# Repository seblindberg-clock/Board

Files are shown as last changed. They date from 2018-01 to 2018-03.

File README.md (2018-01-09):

## Clock Board

Mechanical design

## Revisions

Board revisions are kept as tags in git. The board is generally tagged when the files have been sent off for manufacturing. To export a specific revision, simply run

```
$ git archive --format zip -o /path/to/rev-a.zip 4d268f
```

where the hash of the tag can be found by running `git show rev-a` for the specific tag.

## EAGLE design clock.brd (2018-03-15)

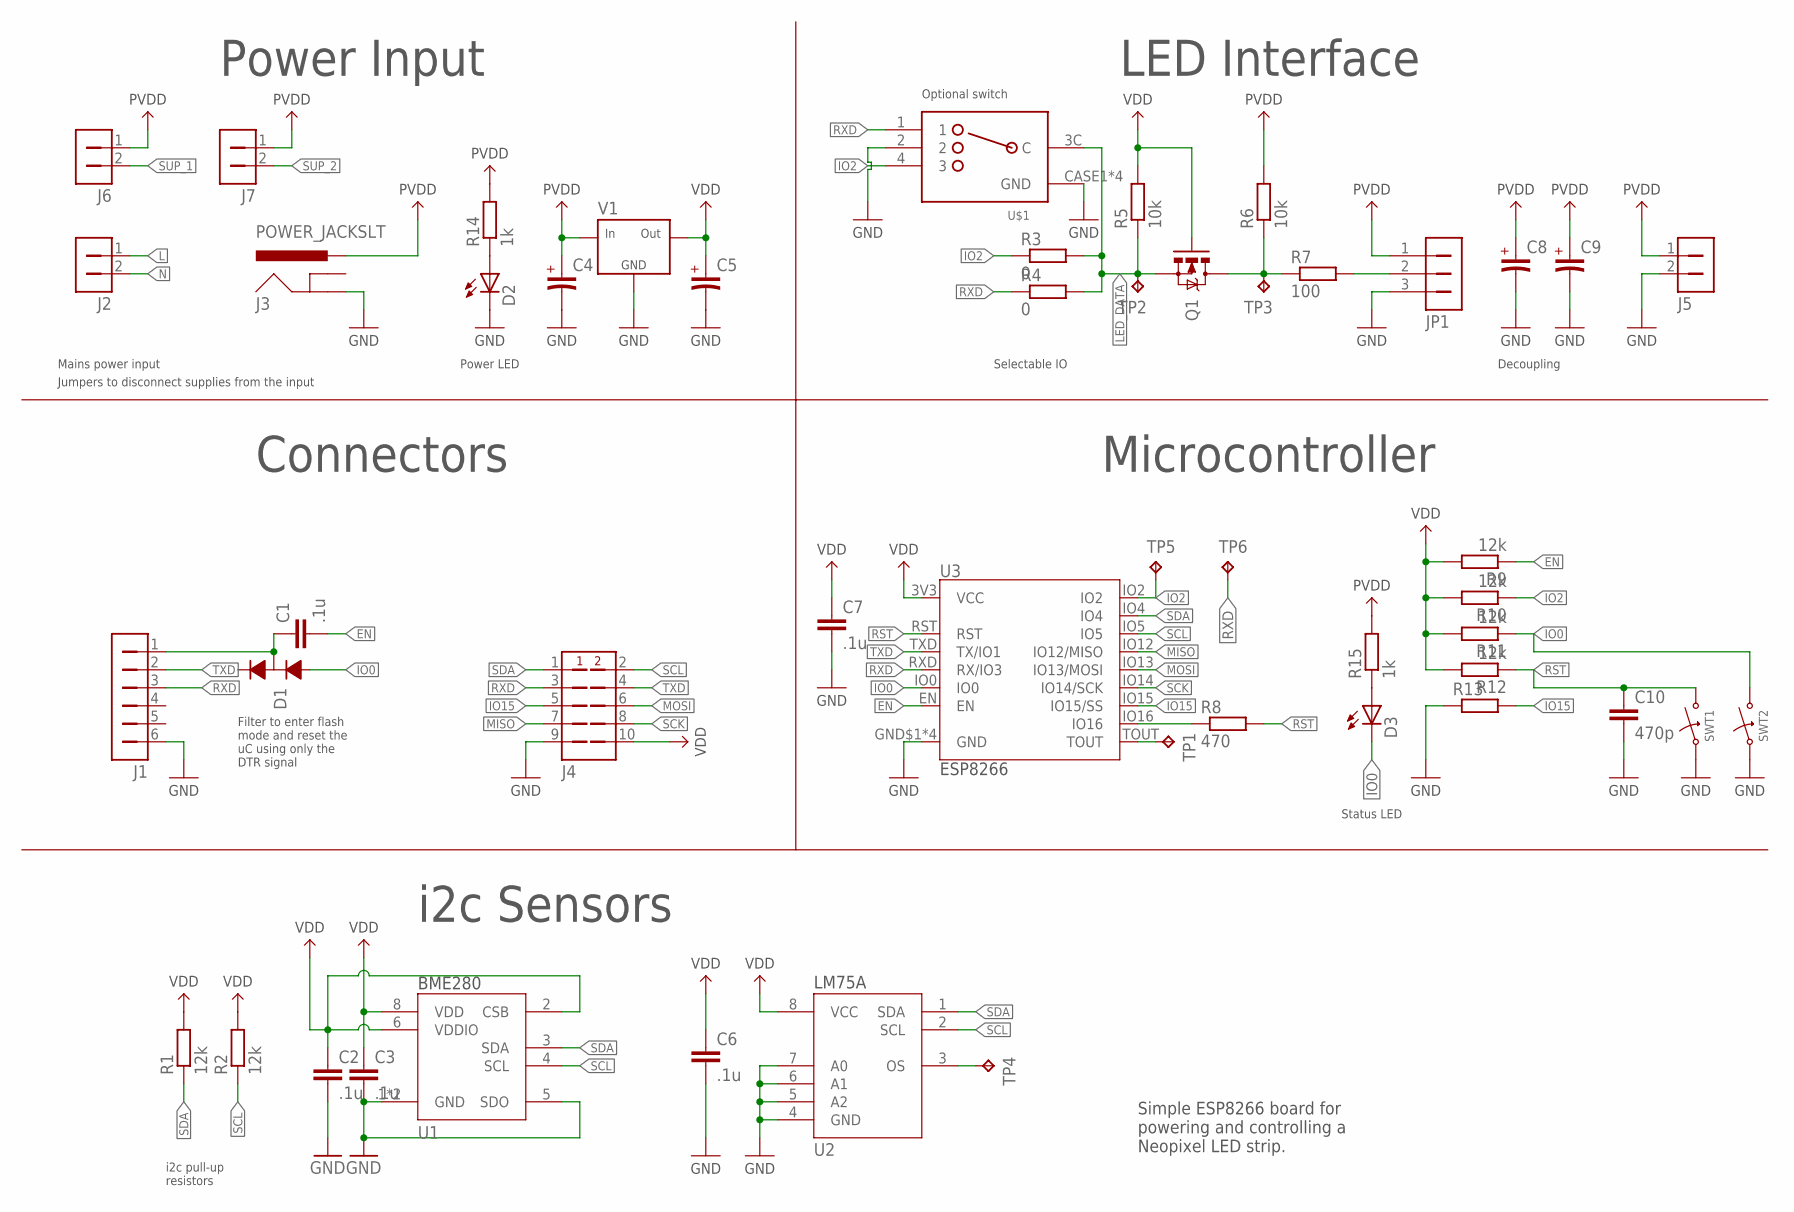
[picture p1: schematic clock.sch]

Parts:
C1, C2, C3, C6, C7: .1u; 0603
C4, C5: C_POL_1206; 1206_POL
C8, C9: C_POL_AVE_X; AVE_X
C10: 470p; 0603
D1: SBAV99WT1G; SC70
D2, D3: LED_0805; 0805_LED
J1: 1X6_RIGHT
J2: 1X2_IEC_C8_RIGHT; IEC_C8_RIGHT
J3: POWER_JACKSLT; POWER_JACK_SLOT
J4: 2X5
J5: 1X2_MOLEX_53254
J6, J7: 1X2
JP1: 1X3_MOLEX_53254
Q1: NMOS_2N7002; SOT23
R1, R2, R9, R10, R11, R12: 12k; 0603
R3, R4: 0; 0603
R5, R6: 10k; 0603
R7: 100; 0603
R8: 470; 0603
R13: R_0603; 0603
R14, R15: 1k; 0603
SWT1, SWT2: BUTTON_SMD_2P; BTN_SMD_2PIN
TP1, TP2, TP3, TP4, TP5, TP6: TPTP15R; TP15R
U1: BME280
U2: LM75A_SO8; SO8
U3: ESP8266_13; ESP13
U$1: SWITCH_1P3T_SSSS812201; SSSS812201
V1: NCP1117; TO252

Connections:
EN: C1.2, R9.1, U3.EN
GND: C2.2, C3.2, C4.2, C5.2, C6.2, C7.2, C8.- (2), C9.- (2), C10.2, D2.C, J1.6, J3.GND@2 (GND), J4.9, J5.2, JP1.3, R13.1, SWT1.1, SWT2.1, U1.1 (GND), U1.5 (SDO), U1.7 (GND), U2.4 (GND), U2.5 (A2), U2.6 (A1), U2.7 (A0), U3.GND$1 (GND), U3.GND$2 (GND), U3.GND$3 (GND), U3.GND$4 (GND), U$1.2, U$1.CASE1 (GND), U$1.CASE2 (GND), U$1.CASE3 (GND), U$1.CASE4 (GND), V1.1 (GND)
IO0: D1.1 (ANODE), D3.C, R11.1, SWT2.2, U3.IO0
IO2: R3.1, R10.1, TP5.TP, U3.IO2, U$1.4 (3)
IO15: J4.5, R13.2, U3.IO15 (IO15/SS)
L: J2.1
LED_DATA: Q1.2 (S), R3.2, R4.2, R5.1, TP2.TP, U$1.3C (C)
MISO: J4.7, U3.IO12 (IO12/MISO)
MOSI: J4.6, U3.IO13 (IO13/MOSI)
N: J2.2
unnamed: TP4.TP, U2.3 (OS)
unnamed: Q1.3 (D), R6.1, R7.1, TP3.TP
unnamed: JP1.2, R7.2
unnamed: D2.A, R14.1
unnamed: D3.A, R15.1
unnamed: TP1.TP, U3.TOUT
unnamed: R8.1, U3.IO16
unnamed: C1.1, D1.3 (MIDDLE), J1.1
PVDD: C4.1, C8.+ (1), C9.+ (1), J3.PWR, J5.1, J6.1, J7.1, JP1.1, R6.2, R14.2, R15.2, V1.2 (IN)
RST: C10.1, R8.2, R12.1, SWT1.2, U3.RST
RXD: J1.3, J4.3, R4.1, TP6.TP, U3.RXD (RX/IO3), U$1.1
SCK: J4.8, U3.IO14 (IO14/SCK)
SCL: J4.2, R2.1, U1.4 (SCL), U2.2 (SCL), U3.IO5
SDA: J4.1, R1.1, U1.3 (SDA), U2.1 (SDA), U3.IO4
SUP_1: J6.2
SUP_2: J7.2
TXD: J1.2, J4.4, U3.TXD (TX/IO1)
VDD: C2.1, C3.1, C5.1, C6.1, C7.1, J4.10, Q1.1 (G), R1.2, R2.2, R5.2, R9.2, R10.2, R11.2, R12.2, U1.2 (CSB), U1.6 (VDDIO), U1.8 (VDD), U2.8 (VCC), U3.3V3 (VCC), V1.3 (OUT)

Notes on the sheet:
Selectable IO
LED Interface
Power Input
i2c Sensors
i2c pull-up resistors
Microcontroller
Connectors
Filter to enter flash mode and reset the uC using only the DTR signal
Simple ESP8266 board for powering and controlling a Neopixel LED strip.
Mains power input
Optional switch
Power LED
Decoupling
Status LED
Jumpers to disconnect supplies from the input

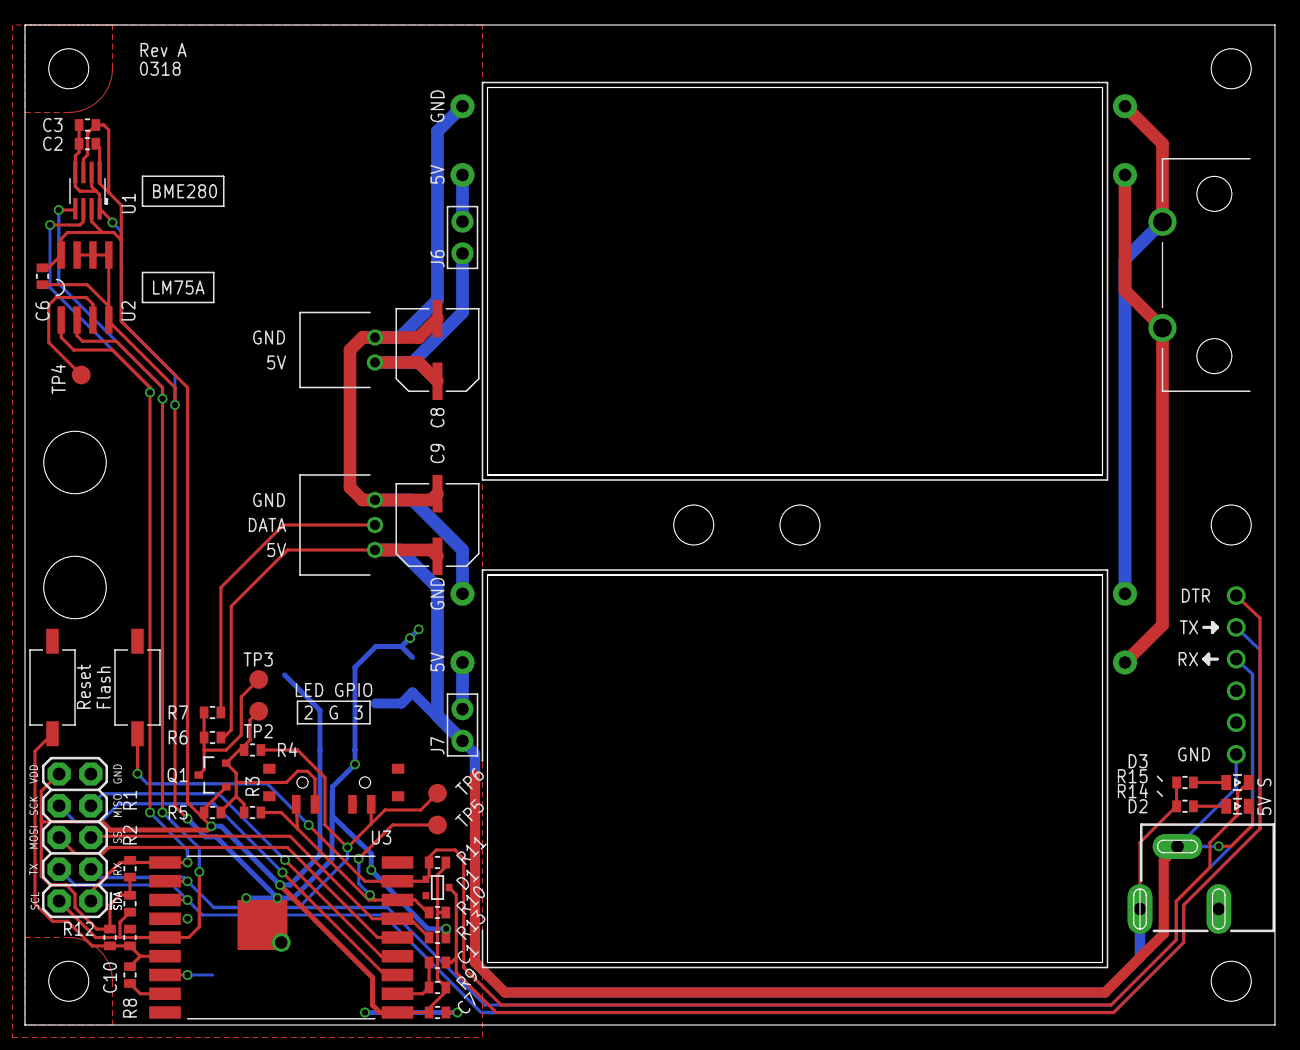
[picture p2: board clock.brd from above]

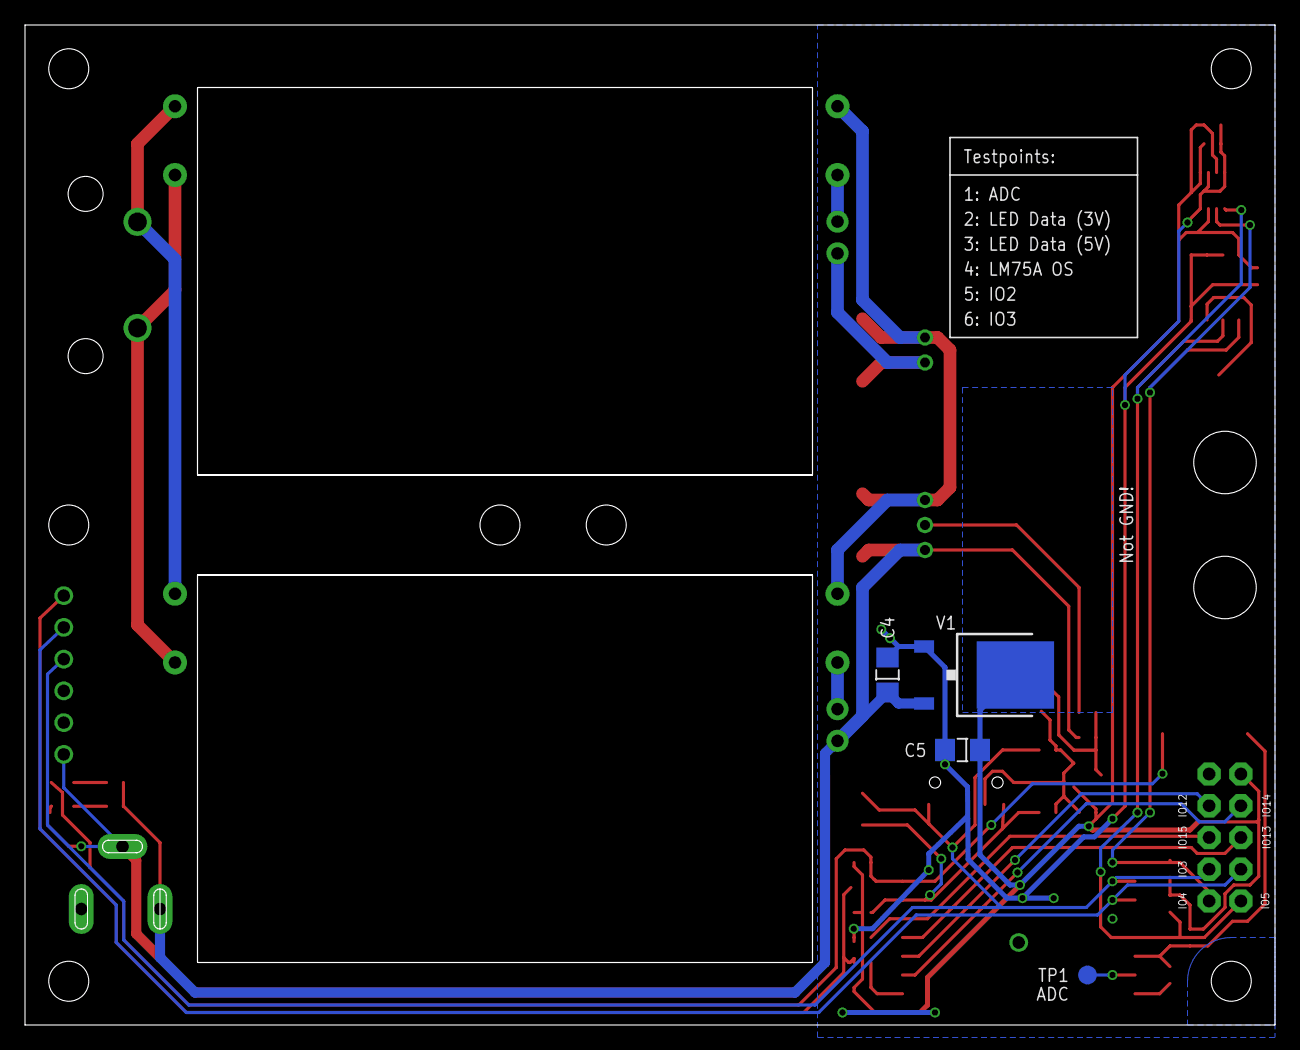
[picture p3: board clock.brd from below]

Board: 2 copper layers, 100.0 x 80.0 mm, 50 parts (4 on the bottom side), 24 nets.

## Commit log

2018-01-09 Initial commit, starting from rev B
    [clock.brd, clock.sch]
2018-01-09 Added some measurements
    [clock.brd]
2018-01-09 Added a power led and some silkscreen to make the footprints for the temperature sensors more obvious
    [clock.brd, clock.sch]
2018-01-09 Changed revision since rev A was never actually ordered and tested
    [clock.brd]
2018-03-15 Added a status LED to IO0
    [clock.brd, clock.sch]
2018-03-15 Increased the safety margin between the live side of the power supply and the isolated 5 v rail
    [clock.brd]
2018-03-15 Added testpoints to IO2 and IO3
    [clock.brd, clock.sch]
2018-03-15 Worked on the silk
    [clock.brd, clock.sch]
2018-03-15 Switched to the new footprint for the ESP8266
    [clock.brd, clock.sch]
2018-03-15 Added silk and milling around the cutouts, just to be clear
    [clock.brd]

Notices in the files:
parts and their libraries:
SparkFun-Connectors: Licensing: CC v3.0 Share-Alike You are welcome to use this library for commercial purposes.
